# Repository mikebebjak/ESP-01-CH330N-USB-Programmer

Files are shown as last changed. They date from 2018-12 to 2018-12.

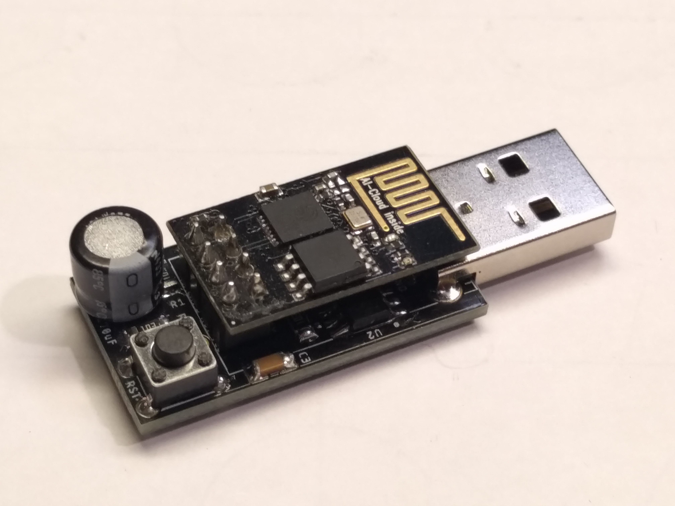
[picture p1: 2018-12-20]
IMG_20181220_100449.jpg

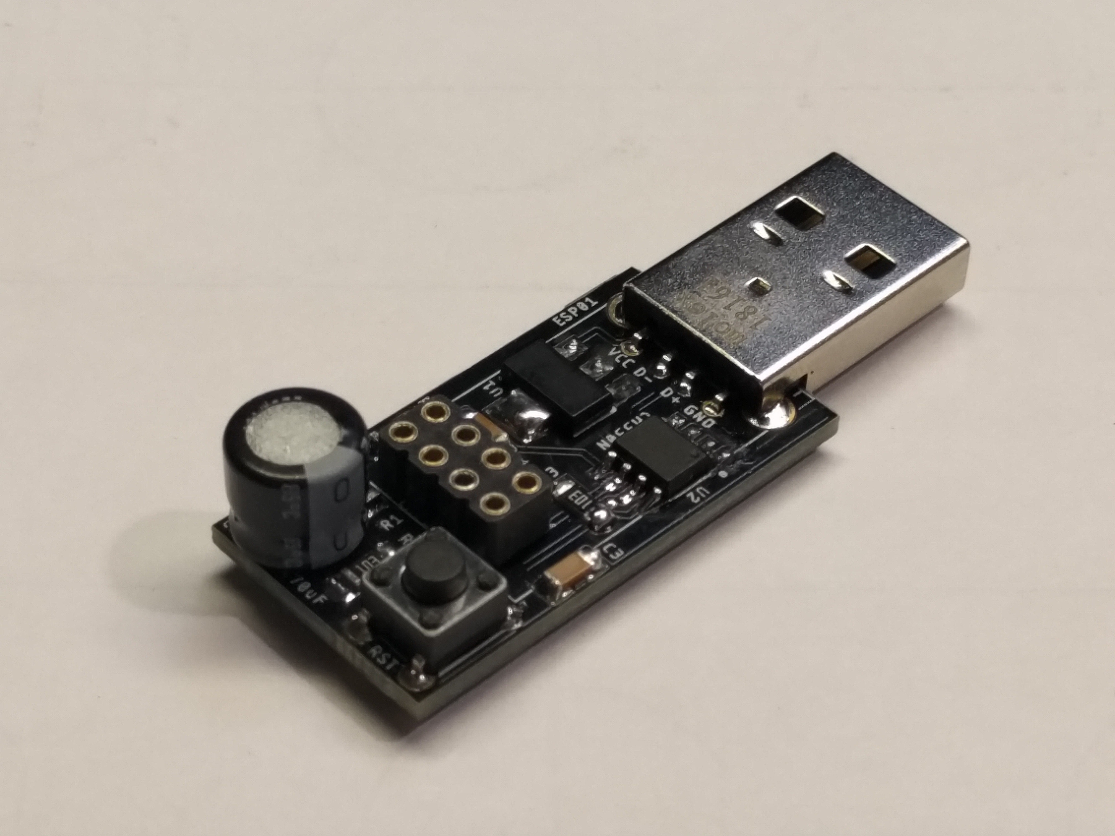
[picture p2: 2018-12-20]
IMG_20181220_100402.jpg

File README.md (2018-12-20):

# ESP-01-CH330N-USB-Programmer

This is a very simple but effective USB programmer for the ESP8266-01 Wifi microcontroller.
It uses a new CH330N SOIC-8 chip which is very easy to implement in ESP projects at a very low cost with few additional components.
The repository includes datasheet, drivers, schematics, Eagle board files and gerbers as well as an Eagle library file for the CH330N.
The drivers used for the CH330N are the same as the CH341.<br>

You can purchase the CH330N at: https://lcsc.com/product-detail/USB_CH330N_C108996.html<br>

You will need:<br>

1x CH330N USB transceiver<br>
1x AMS1117 TO-223 3.3V regulator<br>
1x Molex USB-A through-hole connector<br>
1x 8-pin 2mm socket for the ESP<br>
4x 10K 1206 resistors (for pullups and pulldowns)<br>
2x 0.1uF 1206 capacitors<br>
1x 6mm through-hole momentary push button for the reset button<br>
1x large electrolytic capacitor (220uF or higher at 6.3V min.)<br><br>
GPIO 0 is tied to GND permanently so this programmer cannot be used to boot the ESP (though it may sometimes work anyway).

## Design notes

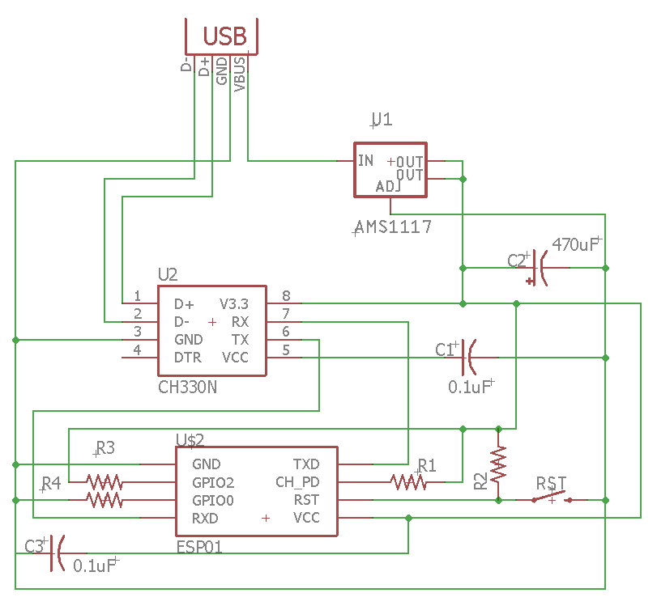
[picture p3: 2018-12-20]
esp01-programmer-schematic.png

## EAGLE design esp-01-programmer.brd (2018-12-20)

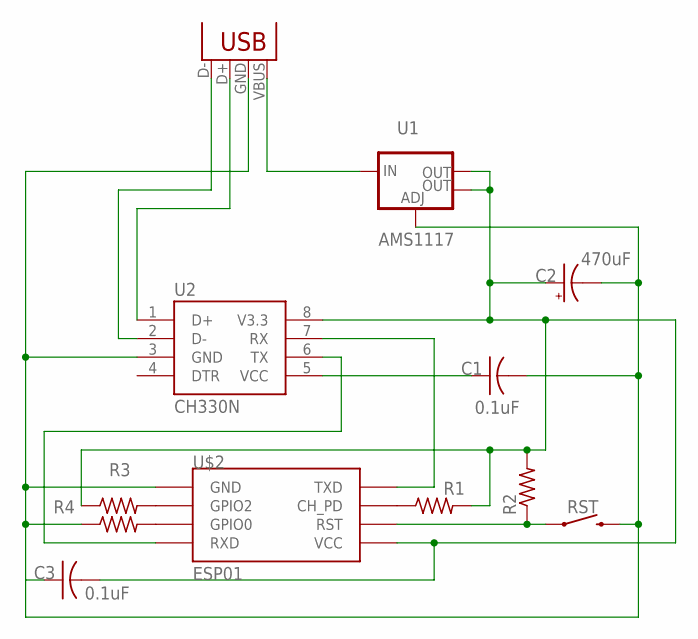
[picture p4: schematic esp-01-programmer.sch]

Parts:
C1, C3: 0.1uF; C1206
C2: 470uF; E2,5-6
R1, R2, R3, R4: R-US_R1206; R1206
RST: MOMENTARY-SWITCH-SPST-PTH-6.0MM; TACTILE_SWITCH_PTH_6.0MM
U1: AMS1117; SOT223
U2: CH330N; SOIC8
U$2: ESP01
USB-A: USB-A-H

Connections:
3.3V: C2.+, C3.2, R1.2, R2.2, R3.1, U1.2 (OUT), U1.4 (OUT), U2.8 (V3.3), U$2.VCC
D+: U2.1 (D+), USB-A.D+ (D-)
D-: U2.2 (D-), USB-A.D- (D+)
DTR: U2.4 (DTR)
GND: C1.2, C2.-, C3.1, R4.1, RST.3 (2), U1.1 (ADJ), U2.3 (GND), U$2.GND, USB-A.GND (VBUS)
unnamed: R2.1, RST.1, U$2.RST
unnamed: R4.2, U$2.GPIO0
unnamed: R3.2, U$2.GPIO2
unnamed: C1.1, U2.5 (VCC)
unnamed: U2.7 (RX), U$2.TX (TXD)
unnamed: U2.6 (TX), U$2.RX (RXD)
unnamed: R1.1, U$2.CH_PD
VUSB: U1.3 (IN), USB-A.VBUS (GND)

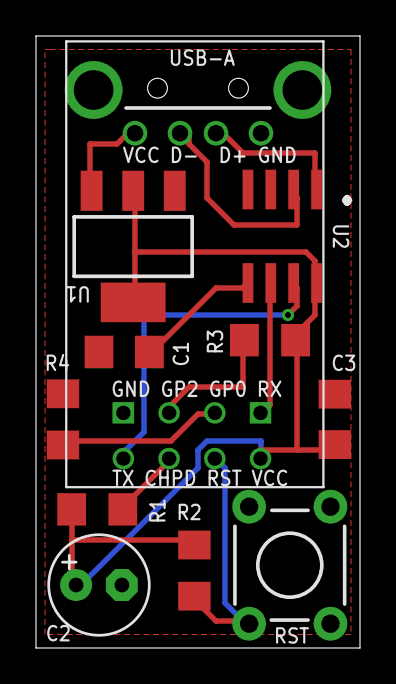
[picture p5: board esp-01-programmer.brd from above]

Board: 2 copper layers, 18.0 x 34.0 mm, 12 parts (0 on the bottom side), 12 nets.

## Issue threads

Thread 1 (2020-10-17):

Schematic symbol shows DTR

Spargue, 2020-10-17:
the symbol shows DTR but the datasheet shows RTS.

mikebebjak, 2020-10-20:
Sorry, I must have missed that when I created the library in Eagle. Either way it doesn't matter because according to their datasheet this pin is left floating/unconnected in the programmer.

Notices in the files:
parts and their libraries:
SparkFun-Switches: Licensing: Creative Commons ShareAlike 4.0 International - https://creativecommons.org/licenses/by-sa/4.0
